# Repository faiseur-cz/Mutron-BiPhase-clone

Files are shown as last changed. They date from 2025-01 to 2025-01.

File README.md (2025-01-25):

# Mutron-BiPhase-clone
DIY clone of the famous phaser

I started a thread at modwiggler, feel free to participate over there :
https://www.modwiggler.com/forum/viewtopic.php?t=290870

Bi-Phase clone by f aiseur - PANEL
Bi-Phase clone by f aiseur - MAIN PCB
Bi-Phase clone by f aiseur - IO PCB
Bi-Phase clone by f aiseur - backPANEL
Bi-Phase clone by f aiseur - MAIN PCB Schematics
Bi-Phase clone by f aiseur - IO PCB Schematics

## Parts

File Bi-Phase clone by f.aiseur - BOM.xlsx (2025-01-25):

Designator | Footprint | Qty | Designation | Mouser Links | Price | Alternatives | Price
Capacitors
FILM
C2,C25 | C_Rect_L7.0mm_W2.0mm_P5.00mm | 2 | 100nf
C21,C30 | C_Rect_L7.2mm_W2.5mm_P5.00mm_FKS2… | 2 | 150nf
C24,C1 | C_Rect_L7.2mm_W2.5mm_P5.00mm_FKS2… | 2 | 47nf
C9,C12,C19,C17,C8,C18,C10,C14,C7,C15,C16,C11 | C_Rect_L7.2mm_W2.5mm_P5.00mm_FKS2… | 12 | 6.8nf
C42,C20,C43,C44,C13 | C_Rect_L7.2mm_W2.5mm_P5.00mm_FKS2… | 5 | 470nf
ELECTRO
C34,C39,C89,C88 | CP_Radial_D5.0mm_P2.50mm | 4 | 47uf – 25v
C76,C75 | CP_Radial_D5.0mm_P2.50mm | 2 | 10uf
C85 | CP_Radial_D5.0mm_P2.50mm | 1 | 2.2uf – 50v
C32,C23 | C_Radial_D6.3mm_H7.0mm_P2.50mm | 2 | 10uf/25v BIPOLAR | https://eu.mouser.com/ProductDetail/667-ECE-A1HN100U | 0.57
CERAMIC
C59,C41,C78,C56,C53,C69,C67,C55,C49,C77,C54,C72,C63, C64,C46,C71,C48,C73,C68,C47,C40,C58,C66,C57,C52,C62, C61,C74,C70,C51,C45, C65,C60,C50 | C_Disc_D3.0mm_W2.0mm_P2.50mm | 34 | 100nf | https://eu.mouser.com/ProductDetail/594-A104K15X7RF5UAA | 3.67
C26,C3 | C_Rect_L7.2mm_W2.5mm_P5.00mm_FKS2… | 2 | 30pf | https://eu.mouser.com/ProductDetail/80-C325C300JAG5TA | 0.74
C27,C4,C6,C29 | C_Rect_L7.2mm_W2.5mm_P5.00mm_FKS2… | 4 | 1nf | CAN BE FILM
C28,C5 | C_Rect_L7.2mm_W2.5mm_P5.00mm_FKS2… | 2 | 3.3nf | https://eu.mouser.com/ProductDetail/810-FG18C0G1H332JNT0 | 0.57
C31,C22 | C_Rect_L7.2mm_W2.5mm_P5.00mm_FKS2… | 2 | 470pf
Diodes
D8,D5,D11,D12,D7,D9,D3,D6,D13,D10,D4 | D_DO-35_SOD27_P7.62mm_Horizontal | 11 | 1N4148
Connectors
IDC13,IDC22,IDC23,IDC33 | IDC-Header_2x05_P2.54mm_Vertical | 3 | Conn_02x05_Odd_Even
LEDs / LDRs
ldr32,ldr34,ldr42,ldr46,ldr44,R16,ldr36,R60,ldr43,ldr45,ldr41, ldr31,ldr33,ldr35 | R_LDR_4.9x4.2mm_P2.54mm_Vertical | 14 | LDR |  |  | https://www.gmelectronic.com/v/1495847/ldr5516-photoresistor | 3.32 | https://www.gmelectronic.com/v/1495846/ldr5549-photoresistor | 3.32
LED-ON-B1,LED-IND-B1,LED-IND-A1,LED-ON-A1, LDR-DRIVE-B1, LDR-DRIVE-A1,PM4,PM3 | LED_D5.0mm | 8 | 5mm | https://eu.mouser.com/ProductDetail/604-WP7113GD | 1.56
Transistors
Q4,Q1,Q3,Q2 | TO-92_Inline_Wide | 4 | BC550C
Resistors
R101 | R_Axial_DIN0207_L6.3mm_D2.5mm_P7.62mm_Horizontal | 1 | 120r
R103,R87,R121,R56,R11 | R_Axial_DIN0207_L6.3mm_D2.5mm_P7.62mm_Horizontal | 5 | 560r
R106 | R_Axial_DIN0207_L6.3mm_D2.5mm_P7.62mm_Horizontal | 1 | 18k
R115,R117 | R_Axial_DIN0207_L6.3mm_D2.5mm_P7.62mm_Horizontal | 2 | 33k
R119,R113 | R_Axial_DIN0207_L6.3mm_D2.5mm_P7.62mm_Horizontal | 2 | 120k
R125,R122,R132,R133,R135,R134 | R_Axial_DIN0207_L6.3mm_D2.5mm_P7.62mm_Horizontal | 6 | 1k8
R127,R123,R124,R126 | R_Axial_DIN0207_L6.3mm_D2.5mm_P7.62mm_Horizontal | 4 | 100k
R129,R83,R84,R130 | R_Axial_DIN0207_L6.3mm_D2.5mm_P7.62mm_Horizontal | 4 | 12r
R20,R40,R38,R39,R58,R3,R49,R9,R1,R35,R33,R8,R14,R52, R61,R7,R91, R41,R18,R31,R19,R37,R10,R22,R5,R6,R32,R23,R42,R55,R17,R24,R36,R21,R54,R12,R34 | R_Axial_DIN0207_L6.3mm_D2.5mm_P7.62mm_Horizontal | 37 | 4k7
R43 | R_Axial_DIN0207_L6.3mm_D2.5mm_P2.54mm_Vertical | 1 | 220k
R53,R4,R15,R59,R112 | R_Axial_DIN0207_L6.3mm_D2.5mm_P7.62mm_Horizontal | 5 | 390k
R57,R13 | R_Axial_DIN0207_L6.3mm_D2.5mm_P7.62mm_Horizontal | 2 | 6k2
R62,R50 | R_Axial_DIN0207_L6.3mm_D2.5mm_P7.62mm_Horizontal | 2 | 12k
R68,R86,R75,R100 | R_Axial_DIN0207_L6.3mm_D2.5mm_P7.62mm_Horizontal | 4 | 10k
R70,R81 | R_Axial_DIN0207_L6.3mm_D2.5mm_P7.62mm_Horizontal | 2 | 2k2
R76,R111,R69,R98 | R_Axial_DIN0207_L6.3mm_D2.5mm_P7.62mm_Horizontal | 4 | 68k
R77,R85,R110,R118,R96,R74,R67,R82,R107,R99,R120 | R_Axial_DIN0207_L6.3mm_D2.5mm_P7.62mm_Horizontal | 11 | 47k
R78,R47,R71,R45,R48,R44,R25,R30,R28,R27,R46,R26,R29 | R_Axial_DIN0207_L6.3mm_D2.5mm_P7.62mm_Horizontal | 13 | 220k
R72, R79 | R_Axial_DIN0207_L6.3mm_D2.5mm_P10.16mm_Horizontal | 2 | 220r 1/2W
R88 | R_Axial_DIN0207_L6.3mm_D2.5mm_P7.62mm_Horizontal | 1 | 130r
R89 | R_Axial_DIN0207_L6.3mm_D2.5mm_P7.62mm_Horizontal | 1 | 24k
R92 | R_Axial_DIN0207_L6.3mm_D2.5mm_P7.62mm_Horizontal | 1 | 1M
R93,R80,R2,R73,R51 | R_Axial_DIN0207_L6.3mm_D2.5mm_P7.62mm_Horizontal | 5 | 3k9
R95,R105,R108,R114,R102,R104,R116,R94,R90 | R_Axial_DIN0207_L6.3mm_D2.5mm_P7.62mm_Horizontal | 9 | 39k
R97 | R_Axial_DIN0207_L6.3mm_D2.5mm_P7.62mm_Horizontal | 1 | 36k
Switches
SW1 | 7211SYCQE / 100DP6T1B1M1QEH | 1 | SP3T-C&K-7211 | https://www.mouser.fr/ProductDetail/612-100-L1111 | 5.41
SW2 | 100SP1T1B4M2QE | 1 | RATE CONTROL | https://eu.mouser.com/ProductDetail/E-Switch/100SP1T1B4M2QE?qs=YXf4ACKMM4xJ0mJK%2FyIa1g%3D%3D | 2.7
SW3 | 100SP1T1B4M2QE | 1 | 100SP1T1B4M2QE | https://eu.mouser.com/ProductDetail/E-Switch/100SP1T1B4M2QE?qs=YXf4ACKMM4xJ0mJK%2FyIa1g%3D%3D | 2.7
SW4 | 100SP1T1B4M2QE | 1 | 100SP1T1B4M2QE | https://eu.mouser.com/ProductDetail/E-Switch/100SP1T1B4M2QE?qs=YXf4ACKMM4xJ0mJK%2FyIa1g%3D%3D | 2.7
SW5 | 7211SYCQE / 100DP6T1B1M1QEH | 1 | SW_SP3T | https://www.mouser.fr/ProductDetail/612-100-L1111 | 5.41
SW6 | 100SP1T1B4M2QE | 1 | SWEEP | https://eu.mouser.com/ProductDetail/E-Switch/100SP1T1B4M2QE?qs=YXf4ACKMM4xJ0mJK%2FyIa1g%3D%3D | 2.7
SW7 | 100DP1T1B1M53QEH | 1 | SW_DPDT_x2 | https://eu.mouser.com/ProductDetail/E-Switch/100DP1T1B1M53QEH?qs=f57gQzlyLiqA8Uf1TAc2Bg%3D%3D | 4.27
SW8 | 100SP1T1B4M2QE | 1 | Bypass-A | https://eu.mouser.com/ProductDetail/E-Switch/100SP1T1B4M2QE?qs=YXf4ACKMM4xJ0mJK%2FyIa1g%3D%3D | 2.7
SW9 | 100SP1T1B4M2QE | 1 | Bypass-B | https://eu.mouser.com/ProductDetail/E-Switch/100SP1T1B4M2QE?qs=YXf4ACKMM4xJ0mJK%2FyIa1g%3D%3D | 2.7
Trimmers
TR10,TR4,TR7,TR1,TR3,TR8,TR2 | Potentiometer_Piher_PT-6-V_Vertical | 7 | 10k |  |  | https://www.gmelectronic.com/v/1486452/piher-pt6vk010-carbon-trimmer | 2.86
TR5,TR6 | Potentiometer_Piher_PT-6-V_Vertical | 2 | 1k |  |  | https://www.gmelectronic.com/v/1485473/piher-pt6vk001-carbon-trimmer | 0.96
TR9 | Potentiometer_Piher_PT-6-V_Vertical | 1 | 22k |  |  | https://www.gmelectronic.com/v/1486453/piher-pt6vk025-carbon-trimmer | 0.48
ICs
U11 | DIP-8_W7.62mm_Socket | 1 | TL072 |  |  | https://www.gmelectronic.com/v/1490183/texas-instruments-tl072cp | 0.76
U2,U6,U15,U13,U4,U1,U3,U16,U9,U7,U12,U10,U14,U8,U5 | DIP-8_W7.62mm_Socket | 15 | RC4558 | https://eu.mouser.com/ProductDetail/595-RC4558P | 2.51 | https://www.gmelectronic.com/v/1487663/texas-instruments-rc4558p | 3.68
Potentiometers
VR1 | Potentiometer_Alpha_RD901F-40-00D_Single_Vertical | 1 | B25k |  | 4.44
VR3 | Potentiometer_Alpha_RD901F-40-00D_Single_Vertical | 1 | A25k |  | 4.44
VR5,VR4,VR6,VR2 | Potentiometer_Alpha_RD901F-40-00D_Single_Vertical | 4 | B10k | https://eu.mouser.com/ProductDetail/Alpha-Taiwan/RD901F-40-15R1-B10K-00DL1?qs=1mbolxNpo8c1WX5KjxIjjw%3D%3D | 17.76 | https://eu.mouser.com/ProductDetail/179-PTN091V10115K1B | 4.88
 | TOTAL | 283
IO PCB
Designator | Footprint | Qty | Designation
Capacitors
ELECTRO
C35,C36 | CP_Radial_D12.5mm_P5.00mm | 2 | 1000uf / 35v | https://eu.mouser.com/ProductDetail/Nichicon/UVK1H102MHD?qs=iKytVS9glgaWoTqK7hc9Yg%3D%3D | 1.3
C82,C38,C81,C33,C37 | CP_Radial_D6.3mm_P2.50mm | 5 | 10uf
FILM
C79,C84,C80,C83 | C_Rect_L7.2mm_W2.5mm_P5.00mm_FKS2… | 4 | 100nf | https://eu.mouser.com/ProductDetail/594-A104K15X7RF5UAA | 0.95
C87,C86 | C_Rect_L7.2mm_W2.5mm_P5.00mm_FKS2… | 2 | 15nf
Diodes
D14 | D_DO-41_SOD81_P10.16mm_Horizontal | 1 | 5V1 | https://eu.mouser.com/ProductDetail/512-1N5231B | 0.1 | https://www.gmelectronic.com/v/1489559/semtech-bzx55-c5v1-zener-diode
D19,D1,D16,D17,D18,D2 | D_DO-41_SOD81_P10.16mm_Horizontal | 6 | 1N4004
Connectors
IDC11,IDC21,IDC31 | IDC-Header_2x05_P2.54mm_Vertical | 3 | Conn_02x05_Odd_Even
J1 | BarrelJack_CUI_PJ-102AH_Horizontal | 1 | Barrel_Jack_Switch | https://eu.mouser.com/ProductDetail/490-PJ-102AH | 0.63
J6,J4,J5,J3,J2 | Jack_6.35mm_Neutrik_NRJ6HF_Horizontal | 5 | NRJ6HF | https://eu.mouser.com/ProductDetail/550-20384 | 5.8
J7 | PinHeader_1x03_P2.54mm_Vertical | 1 | Conn_01x03
J8 | Jack_3.5mm_CUI_SJ1-3535NG_Horizontal | 1 | 3.5mm jack | https://eu.mouser.com/ProductDetail/Same-Sky/SJ1-3535NG?qs=WyjlAZoYn50jUmKVsqeRJw%3D%3D | 1.29
JP1 | PinHeader_1x02_P2.54mm_Vertical | 1 | Jumper_2_Open | resistor leg
JP2,JP3 | R_Axial_DIN0207_L6.3mm_D2.5mm_P7.62mm_Horizontal | 2 | grounds link | resistor leg
Resistors
R137,R136 | R_Axial_DIN0207_L6.3mm_D2.5mm_P10.16mm_Horizontal | 2 | 240r
R64,R63 | R_Axial_DIN0207_L6.3mm_D2.5mm_P10.16mm_Horizontal | 2 | 2k6
R65 | R_Axial_DIN0207_L6.3mm_D2.5mm_P10.16mm_Horizontal | 1 | 2k2
R66 | R_Axial_DIN0207_L6.3mm_D2.5mm_P10.16mm_Horizontal | 1 | 47k
Regulators
U17 | TO-220-3_Vertical | 1 | LM317
U18 | TO-220-3_Vertical | 1 | LM337
 | TOTAL | 42
 | TOTAL | 325

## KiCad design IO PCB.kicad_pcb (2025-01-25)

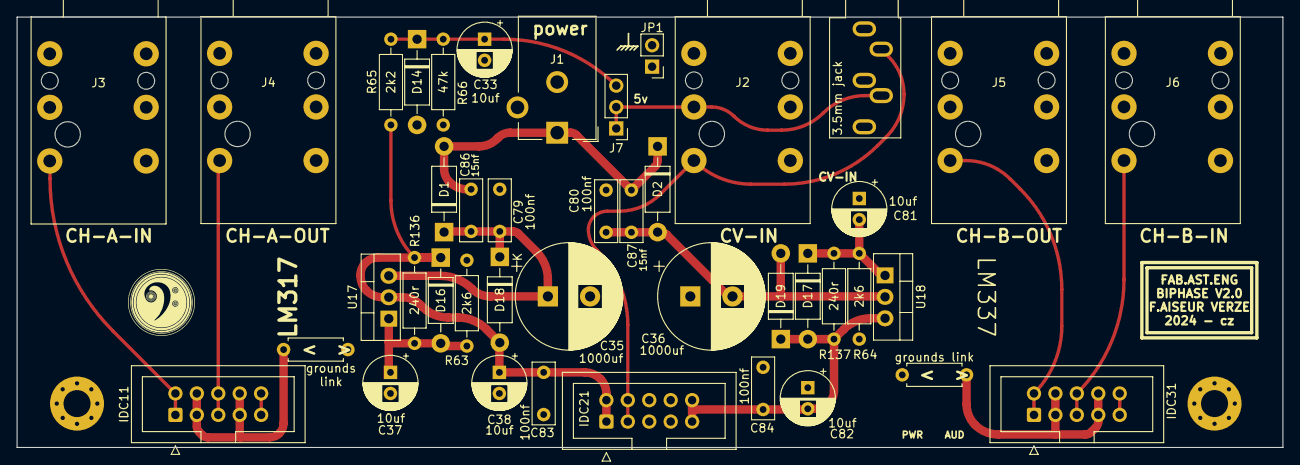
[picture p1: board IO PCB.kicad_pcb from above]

Board: 2 copper layers, 150.0 x 51.0 mm, 44 parts (0 on the bottom side), 18 nets.

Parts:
C33, C37, C38, C81, C82: 10uf; CP_Radial_D6.3mm_P2.50mm
C35, C36: 1000uf; CP_Radial_D12.5mm_P5.00mm
C79, C80, C83, C84: 100nf; C_Rect_L7.2mm_W2.5mm_P5.00mm_FKS2_FKP2_MKS2_MKP2
C86, C87: 15nf; C_Rect_L7.2mm_W2.5mm_P5.00mm_FKS2_FKP2_MKS2_MKP2
D1, D2, D16, D17, D18, D19: 1N4004; D_DO-41_SOD81_P10.16mm_Horizontal
D14: 5V1; D_DO-41_SOD81_P10.16mm_Horizontal
H2, H8: MountingHole_Pad; MountingHole_3.2mm_M3_Pad_Via
IDC11, IDC21, IDC31: Conn_02x05_Odd_Even; IDC-Header_2x05_P2.54mm_Vertical
J1: Barrel_Jack_Switch; BarrelJack_CUI_PJ-102AH_Horizontal
J2, J3, J4, J5, J6: NRJ6HF; Jack_6.35mm_Neutrik_NRJ6HF_Horizontal
J7: Conn_01x03; PinHeader_1x03_P2.54mm_Vertical
J8: 3.5mm jack; Jack_3.5mm_CUI_SJ1-3535NG_Horizontal
JP1: Jumper_2_Open; PinHeader_1x02_P2.54mm_Vertical
JP2, JP3: grounds link; R_Axial_DIN0207_L6.3mm_D2.5mm_P7.62mm_Horizontal
R63, R64: 2k6; R_Axial_DIN0207_L6.3mm_D2.5mm_P10.16mm_Horizontal
R65: 2k2; R_Axial_DIN0207_L6.3mm_D2.5mm_P10.16mm_Horizontal
R66: 47k; R_Axial_DIN0207_L6.3mm_D2.5mm_P10.16mm_Horizontal
R136, R137: 240r; R_Axial_DIN0207_L6.3mm_D2.5mm_P10.16mm_Horizontal
U17: LM317; TO-220-3_Vertical
U18: LM337; TO-220-3_Vertical

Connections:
5v: C33.1, D14.1 (K), J7.3, R65.1, R66.1
GND: IDC11.3, IDC11.4, IDC11.7, IDC11.8, IDC31.3, IDC31.4, IDC31.7, IDC31.8, J3.S, J3.SN, J3.TN, J4.S, J4.SN, J5.S, J5.SN, J5.TN, J6.S, J6.SN, JP2.1 (A), JP3.1 (A)
GND5: C33.2, C35.2, C36.1, C37.2, C38.2, C79.2, C80.1, C81.1, C82.1, C83.2, C84.1, D14.2 (A), H2.1, H8.1, IDC21.5, IDC21.6, IDC21.7, IDC21.8, J1.2, J2.S, J2.SN, J2.TN, J8.S, J8.TN, JP1.1 (A), JP1.2 (B), JP2.2 (B), JP3.2 (B), R63.2, R64.1, R66.2
unnamed: C86.2, C87.1, D1.2 (A), D2.1 (K), J1.1
unnamed: C35.1, C79.1, C86.1, D1.1 (K), D18.1 (K), U17.3 (VI)
unnamed: C37.1, D16.2 (A), R63.1, R136.2, U17.1 (ADJ)
unnamed: C38.1, C83.1, D16.1 (K), D18.2 (A), IDC21.1, IDC21.2, R65.2, R136.1, U17.2 (VO)
unnamed: C82.2, C84.2, D17.2 (A), D19.1 (K), IDC21.9, IDC21.10, R137.2, U18.3 (VO)
unnamed: C81.2, D17.1 (K), R64.2, R137.1, U18.1 (ADJ)
unnamed: C36.2, C80.2, C87.2, D2.2 (A), D19.2 (A), U18.2 (VI)
unnamed: IDC11.1, IDC11.2, J3.T
unnamed: IDC11.5, IDC11.6, J4.T
unnamed: IDC11.9, IDC11.10
unnamed: IDC21.3, IDC21.4, J2.T, J8.T
unnamed: IDC31.1, IDC31.2, J5.T
unnamed: IDC31.5, IDC31.6, J6.T
unnamed: IDC31.9, IDC31.10
unnamed: J2.R, J7.1, J7.2, J8.R
